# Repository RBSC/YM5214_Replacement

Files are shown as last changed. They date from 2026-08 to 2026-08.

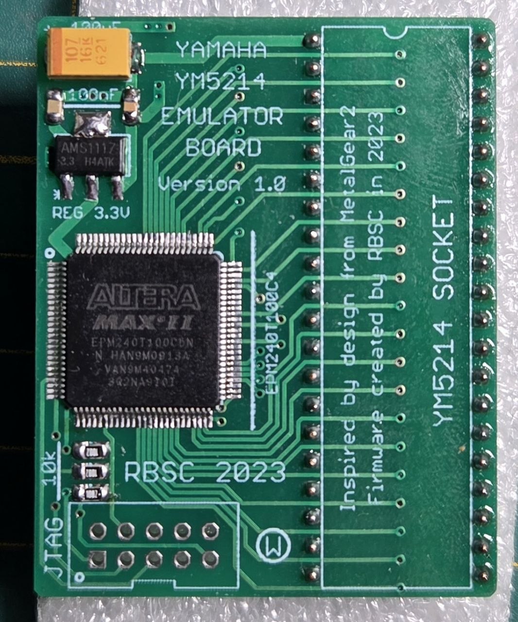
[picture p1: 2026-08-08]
Docs/assembled.jpg

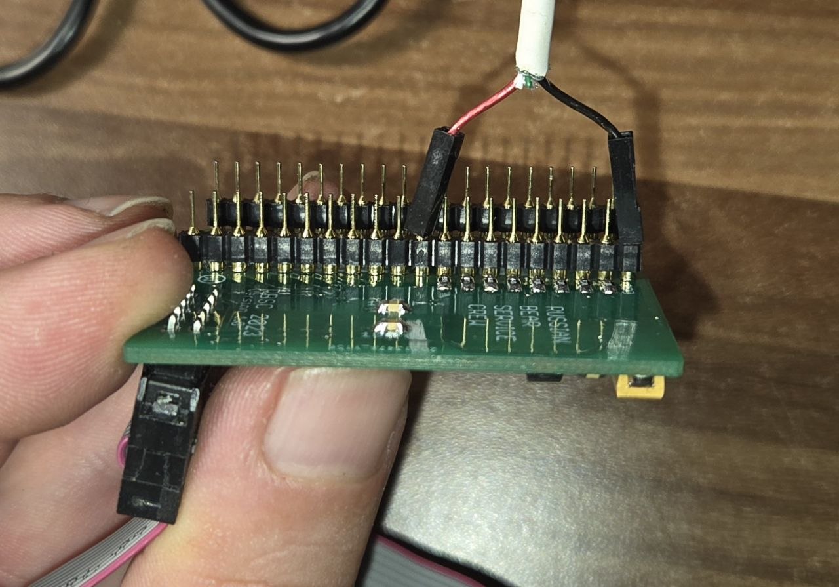
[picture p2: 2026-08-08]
Docs/connecting_cables.jpg

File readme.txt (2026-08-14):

--------------------------------------------------------------------------------
Yamaha YM5214 Emulator Board v1.0
Copyright (c) 2023-2026 RBSC
--------------------------------------------------------------------------------

About
-----

This project's goal was to emulate Yamaha's YM5214 MMC chip that is used in CX5M and similar MSX1 computers as a
memory controller. These chips start to fail in the recent years, so it's good to have an alternative to keep our
CX5Ms alive. The design of this circuit board was inspired by a similar project by MetalGear2, whose website can
be found here: http://mymsx2.free.fr/menu2_msx.html

Assembling and Installing
-------------------------

The board is relatively easy to assemble. Please make sure that you solder all necessary elements and then remove
all flux from the board. The Altera chip on the newly-assembled board must be programmed before use. To do that,
you need to buy a USB Blaster device that can be easily obtained from AliExpress and download the Quartus II
Programmer v15.0 software that can be downloaded from here:

https://sysadminmosaic.ru/en/quartus_ii/quartus_ii#quartusiiweb150

To successfully program the CPLD, you must supply 5 Volts to the board. This can be done using a standard USB-A
cable to which two wires with female Dupont-type connectors have been soldered instead of the miniUSB or microUSB
connector. A cable with broken miniUSB or MicroUSB connector will do fine.

To program the CPLD it is not necessary to solder the JTAG connector or a pin header to the board. It is sufficient
to insert a 2x5-pin header into the "female" connector of the USB Blaster programmer, plug it into the JTAG
connector on the board, and bend it slightly for better contact with the board.

To power the board connect +5V to pin 10 on the YM5214's pin header and connect GND (ground) to pin 1. After that
you can connect the USB Blaster to the JTAG connector. Mind the correct orientation! Now you are ready to program
the CPLD chip.

Select the JTAG mode in the Quartus Programmer software and click the Auto-Detect button. If everything is assembled
and connected correctly, Quartus will detect the EPM240 chip. Next, place the cursor onto the firmware control line
(the one with "EPM240" string), right-click, and select the "Change File" option. A file selection window will
appear. Locate the firmware you need: it can be found in the Firmware folder. Select the .POF file with the firmware
and open it. Set the "Program/Configure," "Verify," and "Blank check" options and click the "Start" button to start
programming.

The CPLD programming usually takes less than a minute. A sign of successful programming is when the progress bar
reaches 100% and no errors appear in the lower window of the user interface. Once the CPLD programming is complete,
first disconnect the programmer and then disconnect the power cable from the board. The board is now fully ready
for use.

To install the board into the CX5M, first remove the broken YM5214 chip and install a 40-pin socket. Do not use sockets
with round pins unless you soldered round pin headers onto the curcuit board. Then carefully insert the curcuit board
into the socket and make sure it sits there firmly. Mind the orientation of the board! When powered on, your CX5M
should boot up in Basic and show 28kb of available RAM if the board is working correctly.

If you are unsure how to interpret or follow the above instructions, then it's advised to ask a more experienced
person for help.

IMPORTANT!
----------

The RBSC provides all the files and information for free, without any liability (see the disclaimer.txt file). The
provided information, software or hardware must not be used for commercial purposes unless permitted by the RBSC.
Producing a small amount of bare boards for personal projects and selling the rest of the batch is allowed without
the permission of RBSC.

When the sources of the tools are used to create alternative projects, please always mention the original source and
the copyright!

Contact information
-------------------

The members of RBSC group Tnt23, Wierzbowsky, Pyhesty, Ptero, GreyWolf, SuperMax, VWarlock, ALSP and DJS3000 can be
contacted via the group's e-mail address:

info@rbsc.su

The group's coordinator could be reached via this e-mail address:

admin@rbsc.su

The group's website can be found here:

https://rbsc.su/
https://rbsc.su/ru

The RBSC's hardware repository can be found here:

https://github.com/rbsc

The RBSC's 3D model repository can be found here:

https://www.thingiverse.com/groups/rbsc/things

-= ! MSX FOREVER ! =-

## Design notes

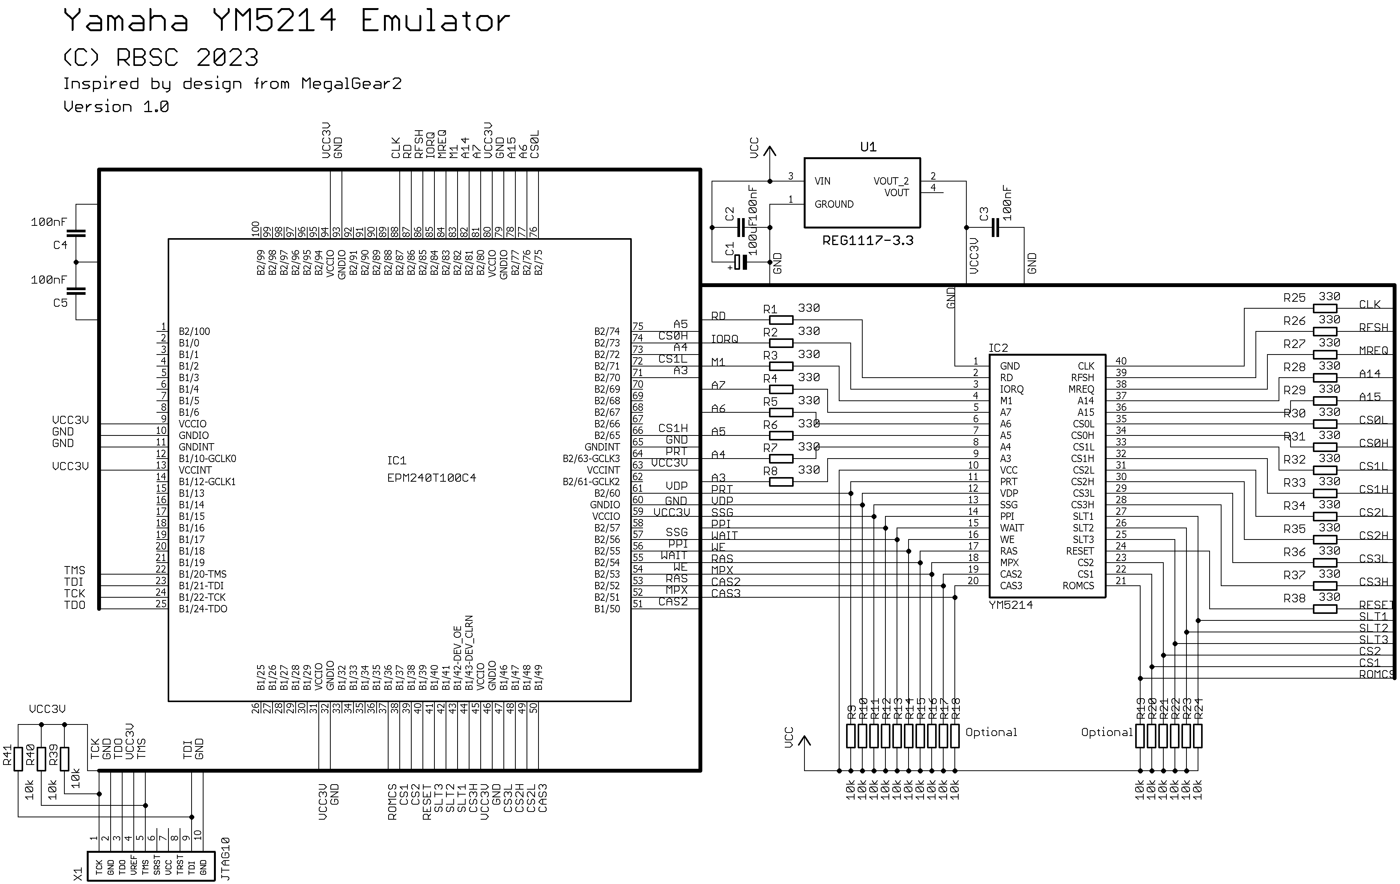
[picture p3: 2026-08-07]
Docs/schematics.png

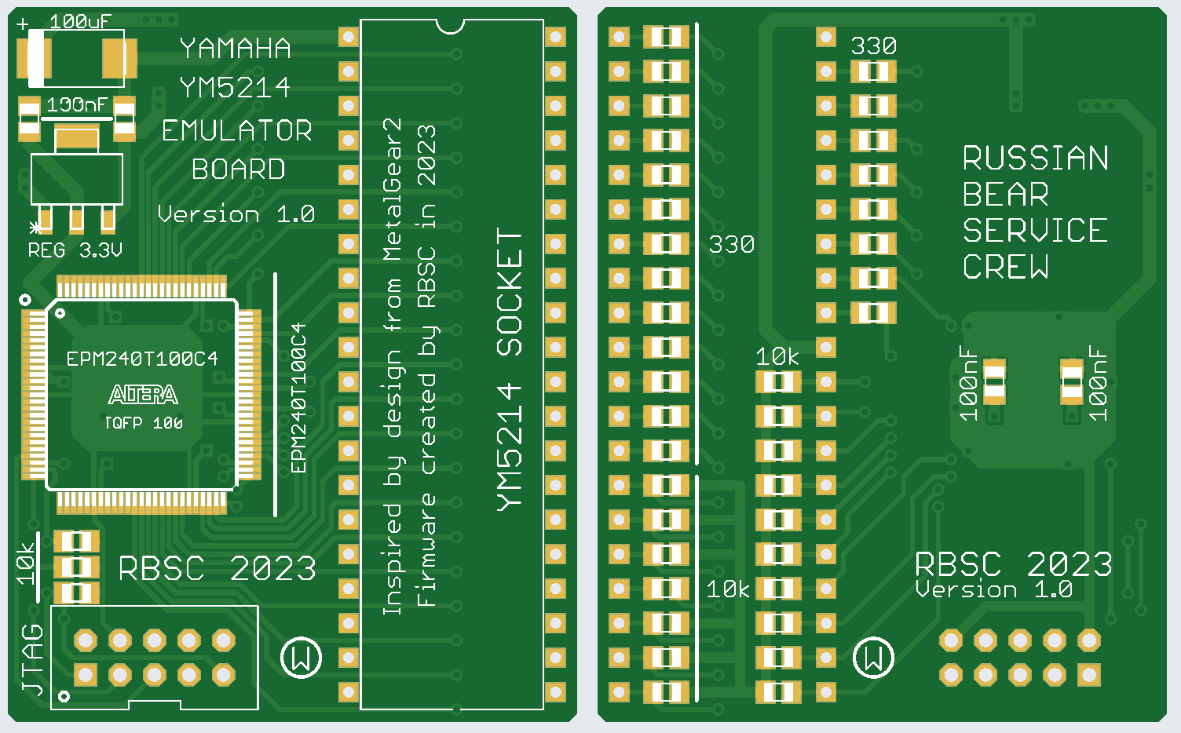
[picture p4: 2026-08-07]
Docs/board.png

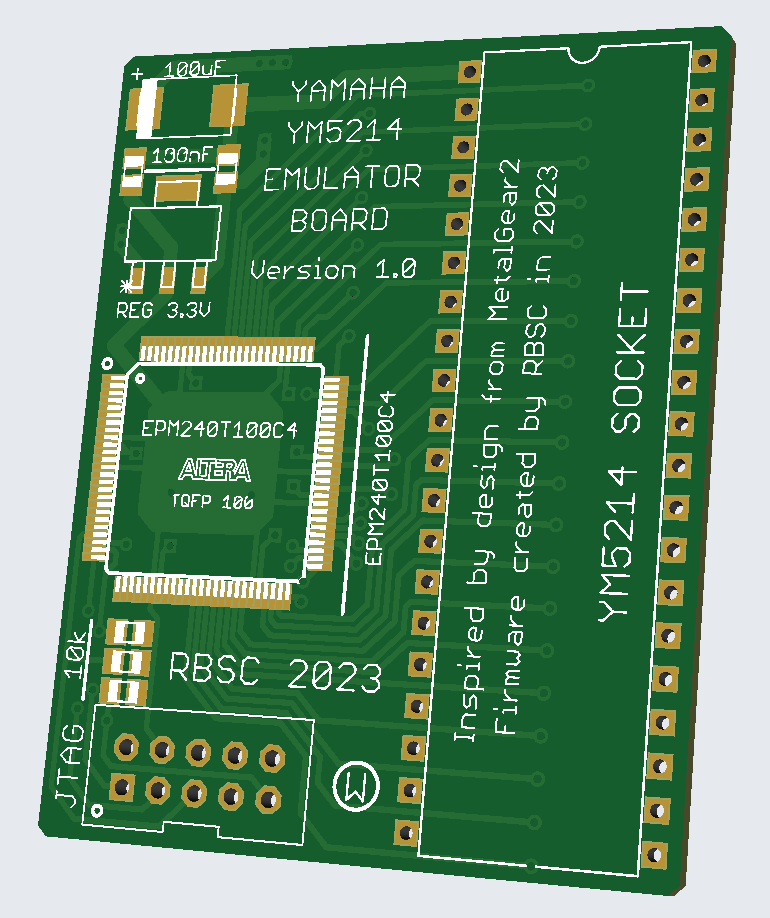
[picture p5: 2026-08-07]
Docs/board_3d.png

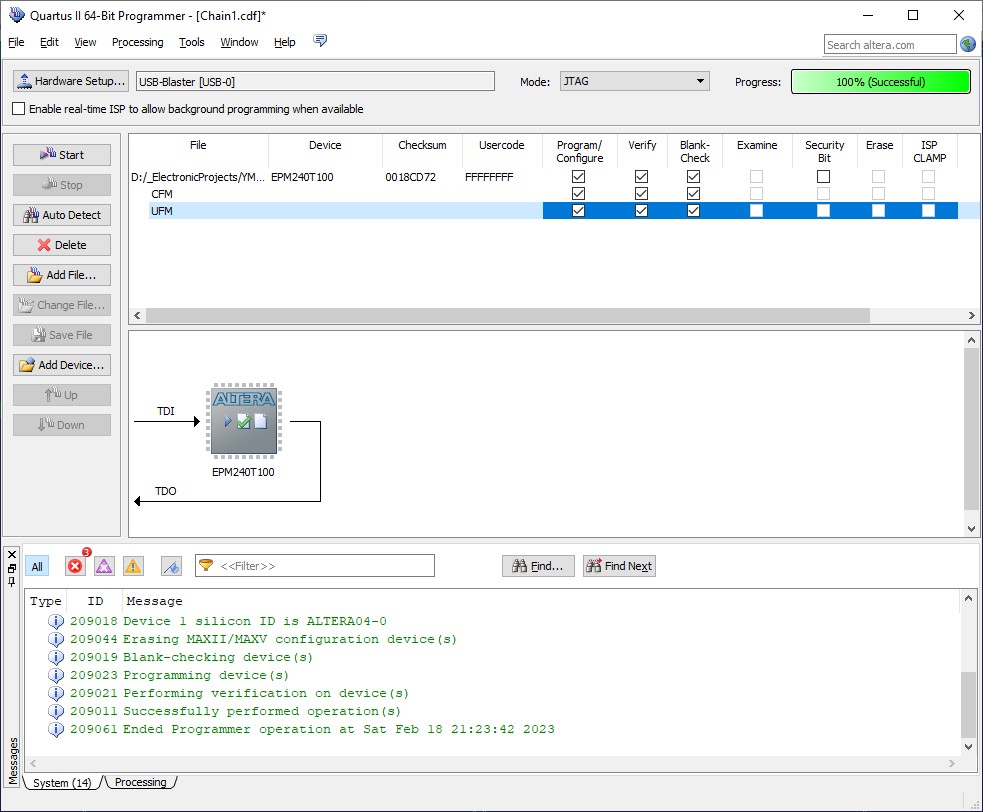
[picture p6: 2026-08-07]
Docs/programming.jpg

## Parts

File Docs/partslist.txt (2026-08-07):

Partlist
--------

Part     Value          Device       Package

C1       100uF          CPOL-EUSMCD  SMC_D
C2       100nF          C-EUC0805    C0805
C3       100nF          C-EUC0805    C0805
C4       100nF          C-EUC0805    C0805
C5       100nF          C-EUC0805    C0805
IC1      EPM240T100C4   EPM240T100C4 TQFP100
CN1      YM5214         YM5214       DIL40
R1       330            R-EU_R0805   R0805
R2       330            R-EU_R0805   R0805
R3       330            R-EU_R0805   R0805
R4       330            R-EU_R0805   R0805
R5       330            R-EU_R0805   R0805
R6       330            R-EU_R0805   R0805
R7       330            R-EU_R0805   R0805
R8       330            R-EU_R0805   R0805
R9       10k            R-EU_R0805   R0805
R10      10k            R-EU_R0805   R0805
R11      10k            R-EU_R0805   R0805
R12      10k            R-EU_R0805   R0805
R13      10k            R-EU_R0805   R0805
R14      10k            R-EU_R0805   R0805
R15      10k            R-EU_R0805   R0805
R16      10k            R-EU_R0805   R0805
R17      10k            R-EU_R0805   R0805
R18      10k            R-EU_R0805   R0805
R19      10k            R-EU_R0805   R0805
R20      10k            R-EU_R0805   R0805
R21      10k            R-EU_R0805   R0805
R22      10k            R-EU_R0805   R0805
R23      10k            R-EU_R0805   R0805
R24      10k            R-EU_R0805   R0805
R25      330            R-EU_R0805   R0805
R26      330            R-EU_R0805   R0805
R27      330            R-EU_R0805   R0805
R28      330            R-EU_R0805   R0805
R29      330            R-EU_R0805   R0805
R30      330            R-EU_R0805   R0805
R31      330            R-EU_R0805   R0805
R32      330            R-EU_R0805   R0805
R33      330            R-EU_R0805   R0805
R34      330            R-EU_R0805   R0805
R35      330            R-EU_R0805   R0805
R36      330            R-EU_R0805   R0805
R37      330            R-EU_R0805   R0805
R38      330            R-EU_R0805   R0805
R39      10k            R-EU_R0805   R0805
R40      10k            R-EU_R0805   R0805
R41      10k            R-EU_R0805   R0805
U1       REG1117-3.3    REG1117-3.3  SOT230P700X180-4N
X1       JTAG10         JTAG10       JTAG

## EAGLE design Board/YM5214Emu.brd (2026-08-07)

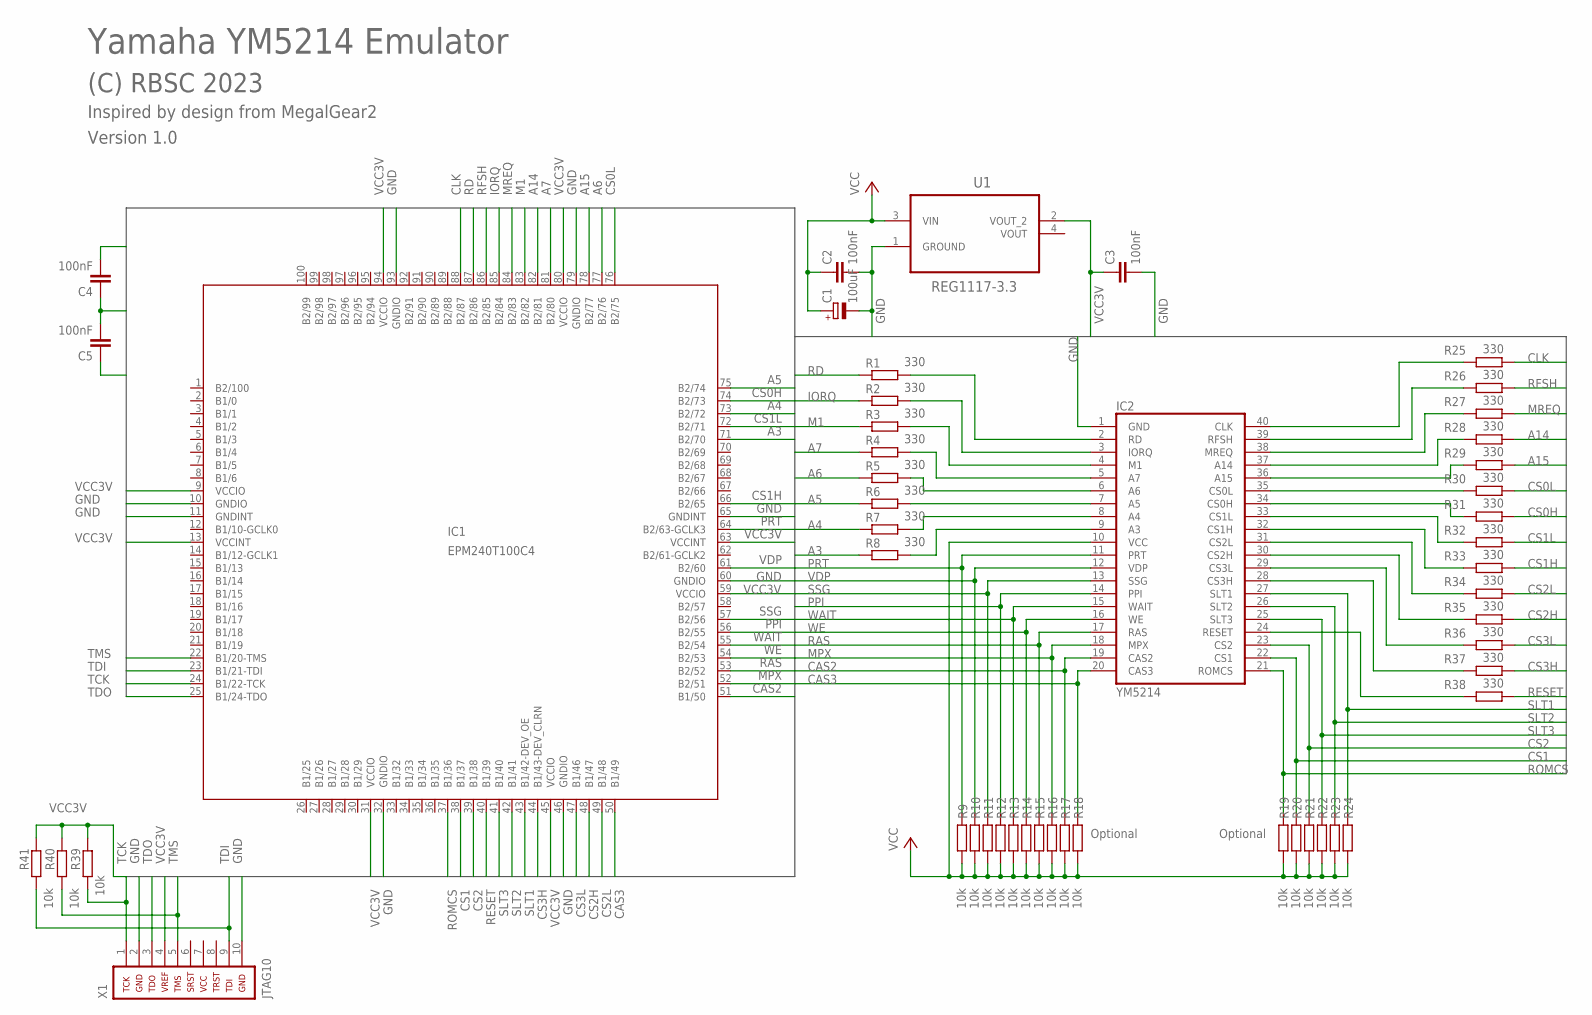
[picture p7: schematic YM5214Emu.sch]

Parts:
C1: 100uF; SMC_D
C2, C3, C4, C5: 100nF; C0805
IC1: EPM240T100C4; TQFP100
IC2: YM5214; DIL40
R1, R2, R3, R4, R5, R6, R7, R8, R25, R26, R27, R28, R29, R30, R31, R32, R33, R34, R35, R36, R37, R38: 330; R0805
R9, R10, R11, R12, R13, R14, R15, R16, R17, R18, R19, R20, R21, R22, R23, R24, R39, R40, R41: 10k; R0805
U1: REG1117-3.3; SOT230P700X180-4N
X1: JTAG10

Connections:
A3: IC1.71 (B2/70), R8.1
A4: IC1.73 (B2/72), R7.1
A5: IC1.75 (B2/74), R6.1
A6: IC1.77 (B2/76), R5.1
A7: IC1.81 (B2/80), R4.1
A14: IC1.82 (B2/81), R28.2
A15: IC1.78 (B2/77), R29.2
CAS2: IC1.51 (B1/50), IC2.19 (CAS2), R17.2
CAS3: IC1.50 (B1/49), IC2.20 (CAS3), R18.2
CLK: IC1.88 (B2/87), R25.2
CS0H: IC1.74 (B2/73), R31.2
CS0L: IC1.76 (B2/75), R30.2
CS1: IC1.38 (B1/37), IC2.22 (CS1), R20.2
CS1H: IC1.66 (B2/65), R33.2
CS1L: IC1.72 (B2/71), R32.2
CS2: IC1.39 (B1/38), IC2.23 (CS2), R21.2
CS2H: IC1.48 (B1/47), R35.2
CS2L: IC1.49 (B1/48), R34.2
CS3H: IC1.44 (B1/43-DEV_CLRN), R37.2
CS3L: IC1.47 (B1/46), R36.2
GND: C1.-, C2.2, C3.2, C4.1, C5.2, IC1.10 (GNDIO), IC1.11 (GNDINT), IC1.32 (GNDIO), IC1.46 (GNDIO), IC1.60 (GNDIO), IC1.65 (GNDINT), IC1.79 (GNDIO), IC1.93 (GNDIO), IC2.1 (GND), U1.1 (GROUND), X1.2, X1.10
IORQ: IC1.85 (B2/84), R2.1
M1: IC1.83 (B2/82), R3.1
MPX: IC1.52 (B2/51), IC2.18 (MPX), R16.2
MREQ: IC1.84 (B2/83), R27.2
unnamed: IC2.2 (RD), R1.2
unnamed: IC2.3 (IORQ), R2.2
unnamed: IC2.4 (M1), R3.2
unnamed: IC2.5 (A7), R4.2
unnamed: IC2.6 (A6), R5.2
unnamed: IC2.7 (A5), R6.2
unnamed: IC2.8 (A4), R7.2
unnamed: IC2.9 (A3), R8.2
unnamed: IC2.24 (RESET), R38.1
unnamed: IC2.28 (CS3H), R37.1
unnamed: IC2.29 (CS3L), R36.1
unnamed: IC2.30 (CS2H), R35.1
unnamed: IC2.31 (CS2L), R34.1
unnamed: IC2.32 (CS1H), R33.1
unnamed: IC2.33 (CS1L), R32.1
unnamed: IC2.34 (CS0H), R31.1
unnamed: IC2.35 (CS0L), R30.1
unnamed: IC2.36 (A15), R29.1
unnamed: IC2.37 (A14), R28.1
unnamed: IC2.38 (MREQ), R27.1
unnamed: IC2.39 (RFSH), R26.1
unnamed: IC2.40 (CLK), R25.1
PPI: IC1.56 (B2/55), IC2.14 (PPI), R12.2
PRT: IC1.64 (B2/63-GCLK3), IC2.11 (PRT), R9.2
RAS: IC1.53 (B2/52), IC2.17 (RAS), R15.2
RD: IC1.87 (B2/86), R1.1
RESET: IC1.40 (B1/39), R38.2
RFSH: IC1.86 (B2/85), R26.2
ROMCS: IC1.37 (B1/36), IC2.21 (ROMCS), R19.2
SLT1: IC1.43 (B1/42-DEV_OE), IC2.27 (SLT1), R24.2
SLT2: IC1.42 (B1/41), IC2.26 (SLT2), R23.2
SLT3: IC1.41 (B1/40), IC2.25 (SLT3), R22.2
SSG: IC1.57 (B2/56), IC2.13 (SSG), R11.2
TCK: IC1.24 (B1/22-TCK), R39.1, X1.1
TDI: IC1.23 (B1/21-TDI), R41.1, X1.9
TDO: IC1.25 (B1/24-TDO), X1.3
TMS: IC1.22 (B1/20-TMS), R40.1, X1.5
VCC: C1.+, C2.1, IC2.10 (VCC), R9.1, R10.1, R11.1, R12.1, R13.1, R14.1, R15.1, R16.1, R17.1, R18.1, R19.1, R20.1, R21.1, R22.1, R23.1, R24.1, U1.3 (VIN)
VCC3V: C3.1, C4.2, C5.1, IC1.9 (VCCIO), IC1.13 (VCCINT), IC1.31 (VCCIO), IC1.45 (VCCIO), IC1.59 (VCCIO), IC1.63 (VCCINT), IC1.80 (VCCIO), IC1.94 (VCCIO), R39.2, R40.2, R41.2, U1.2 (VOUT_2), X1.4
VDP: IC1.61 (B2/60), IC2.12 (VDP), R10.2
WAIT: IC1.55 (B2/54), IC2.15 (WAIT), R13.2
WE: IC1.54 (B2/53), IC2.16 (WE), R14.2

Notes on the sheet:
Optional
(C) RBSC 2023
Version 1.0
Inspired by design from MegalGear2
Yamaha YM5214 Emulator

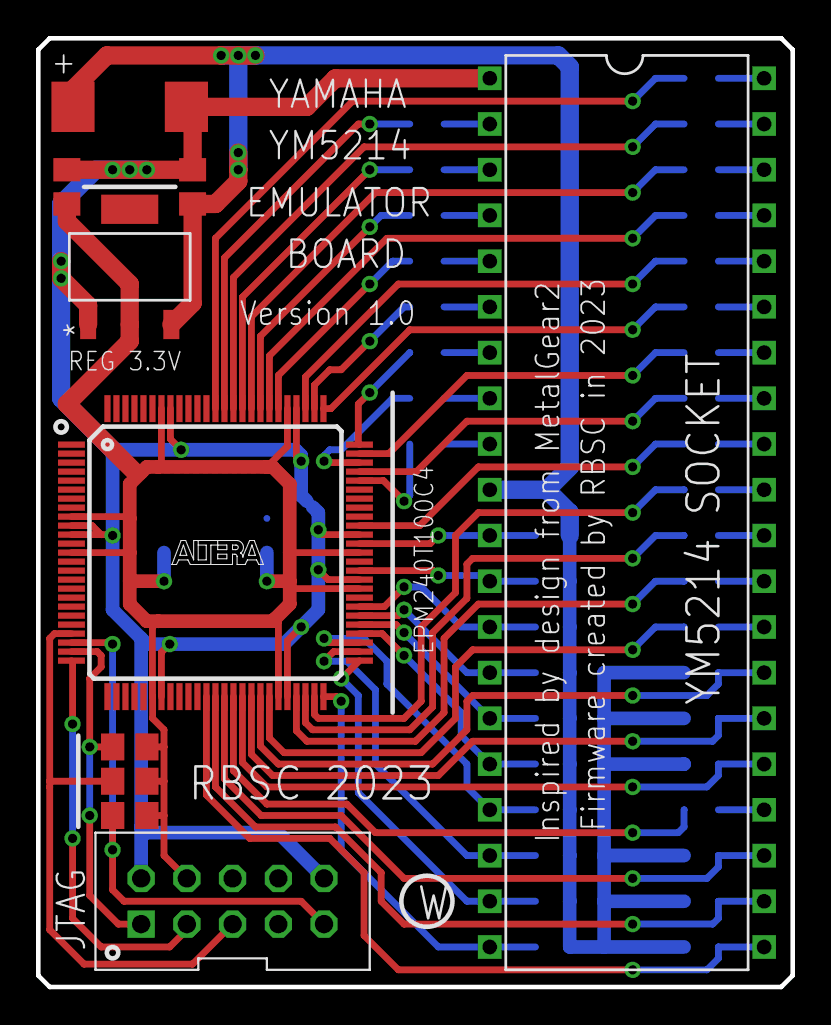
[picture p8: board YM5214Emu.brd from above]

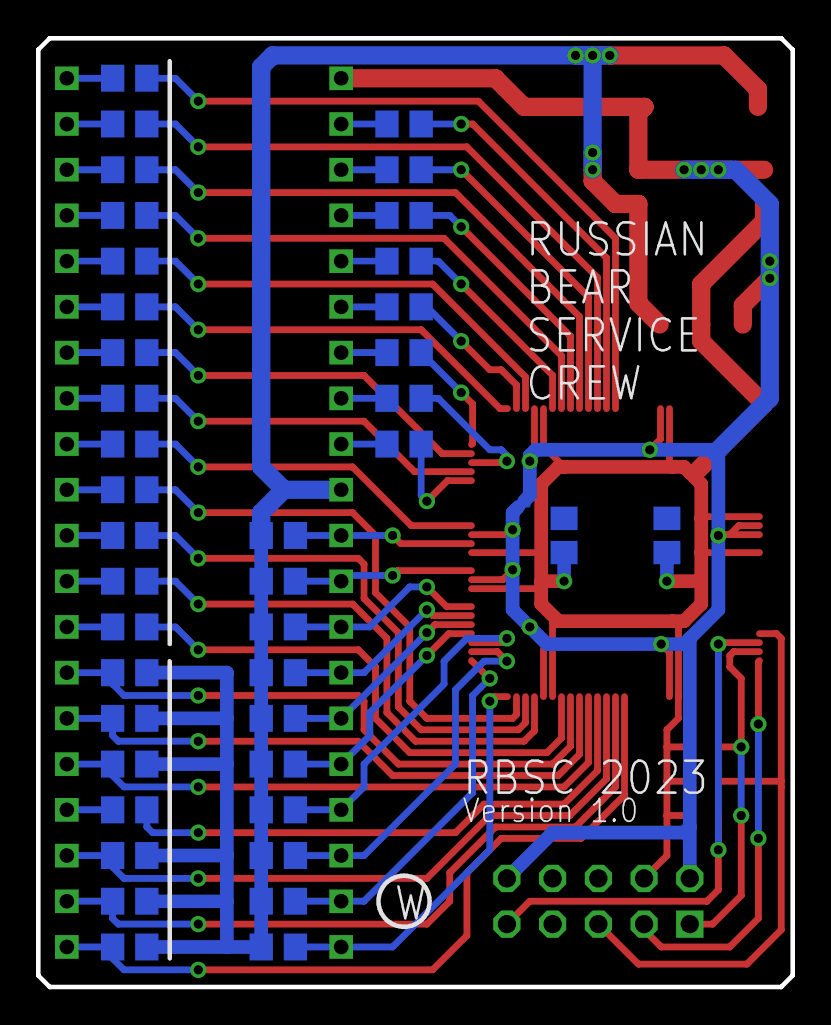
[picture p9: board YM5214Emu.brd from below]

Board: 2 copper layers, 41.9 x 52.7 mm, 50 parts (40 on the bottom side), 67 nets.

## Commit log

2026-08-07 Initial Release 07.08.2026
    Initial release of the project files.
    [YM5214Emu.GBL, YM5214Emu.GBO, YM5214Emu.GBP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]
2026-08-08 Updated 09.08.2026
    Added photos of the board and connections.

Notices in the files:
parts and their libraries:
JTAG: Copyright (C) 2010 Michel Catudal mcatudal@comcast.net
